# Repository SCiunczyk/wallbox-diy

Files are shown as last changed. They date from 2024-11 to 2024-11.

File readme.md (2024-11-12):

### DIV WallBox Wi-Fi ModBus ESP32 proxy

I have finished building my home DIY WallBox based on a great solution from creasol.it called [DombusEVSE](https://www.creasol.it/DomBusEVSE). Creasol has a lot of interesting smart home devices on offer and the solution they have chosen is very much based on the popular ModBus protocol. Unfortunately, in my WallBox it would be difficult for me to apply this solution because I have quite a long distance and I can't lay a cable for a ModBus connection. But fortunately my WallBox location is in range of my home WiFi network. Having already in my Home Assistant other integrations based on ESPHome, I decided to make a proxy adapter for ModBus. I used the XIAO Seed ESP32C3 board and a TTL RS485 adapter as the platform. I "stole" power from the DombusEVSE power supply (13.6V) and used a popular Pololu step-down converter. As I already had a previously purchased 3-phase energy meter with a "pulse" output, I also used the XIAO to measure and record the energy used to charge the EV.

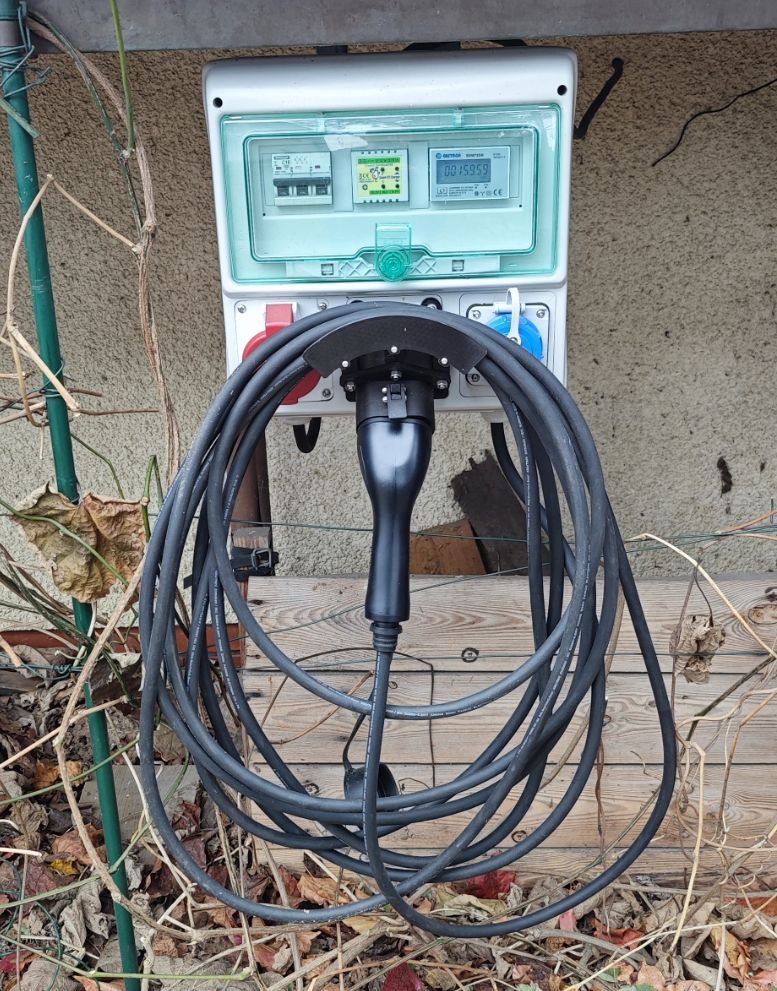
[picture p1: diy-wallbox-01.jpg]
diy-wallbox-01

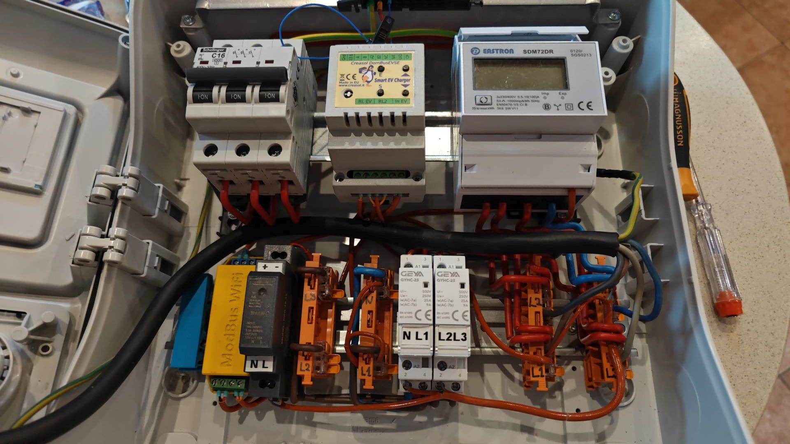
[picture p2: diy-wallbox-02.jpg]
diy-wallbox-02

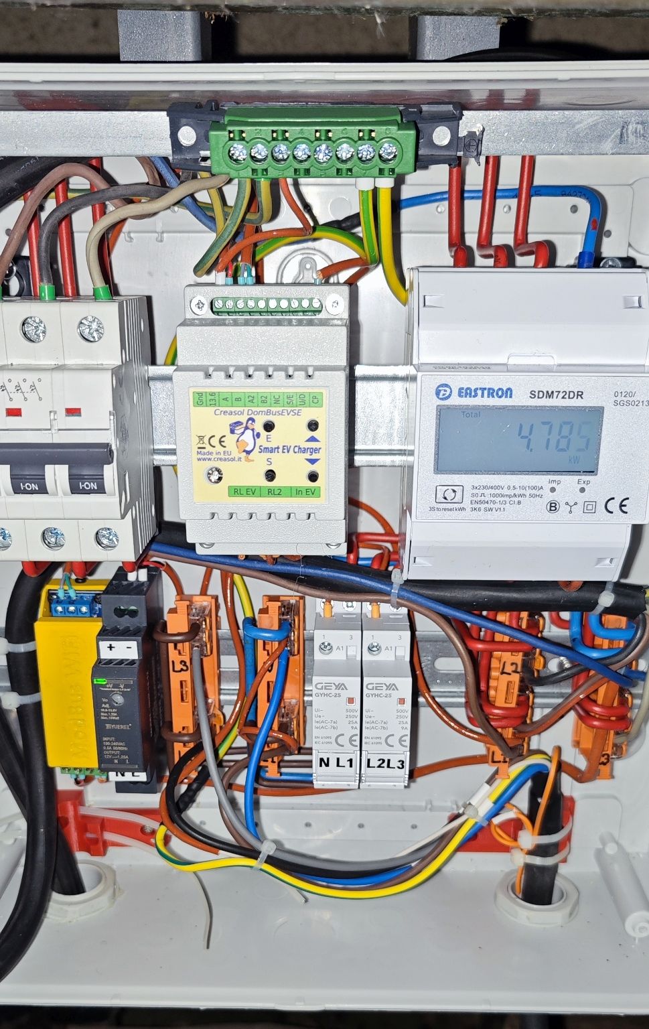
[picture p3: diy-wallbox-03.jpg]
diy-wallbox-03

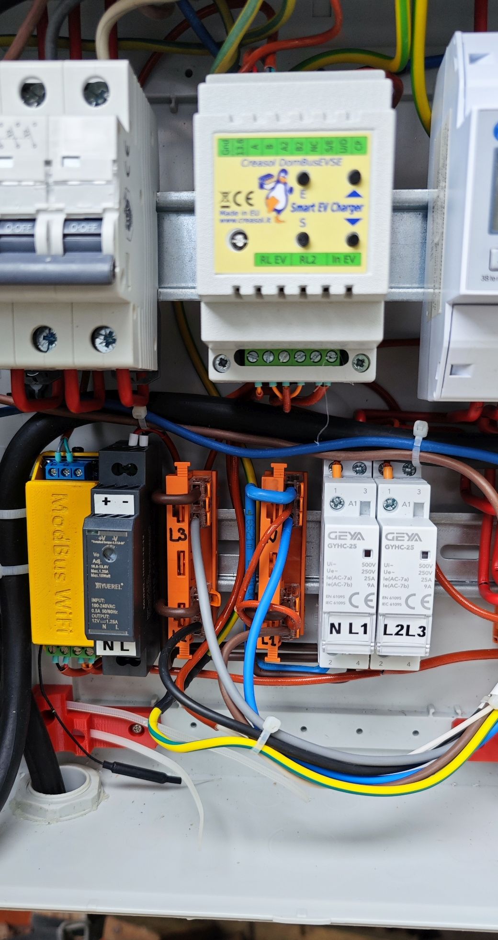
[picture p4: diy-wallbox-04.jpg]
diy-wallbox-04


It all seemed simple and straightforward, but as always life is much more interesting than we imagine.

Creasol.it provides ready-made configurations for HA, so in my first attempt I made a yaml ESPHome based on their ModBus controller https://github.com/CreasolTech/DomBusEVSE_ha.

This worked, but only partially. It seems to me that the ModBus component in ESPHome has a problem reading multiple registers with high addresses. I have described the problem on ESPHome's GitHub: https://github.com/esphome/issues/issues/6351. Registers with low addresses are read and written without problems. Writing to high addresses is correct, the problem is with sequential reading. Interestingly, reading with the custom method works fine. This allowed me to create a workaround for the problem. For high registers I defined a double set of entities. Read-only sensors, which are queried by the custom method, and a complementary numeric set, which is used for writing only.

Of course, this required adapting the original HA configuration files from the creasol.it.

My hardware WallBox is built in a variant that allows switching between single-phase and three-phase charging. I also wanted a mobile version of the dashboard. I took the opportunity to practice building my own dashboard in HA using the famous custom:button-card, custom:layout-card, custom:text-divider-row - all downloadable from HACS.

Desktop version of Home Assistant Dashboard:

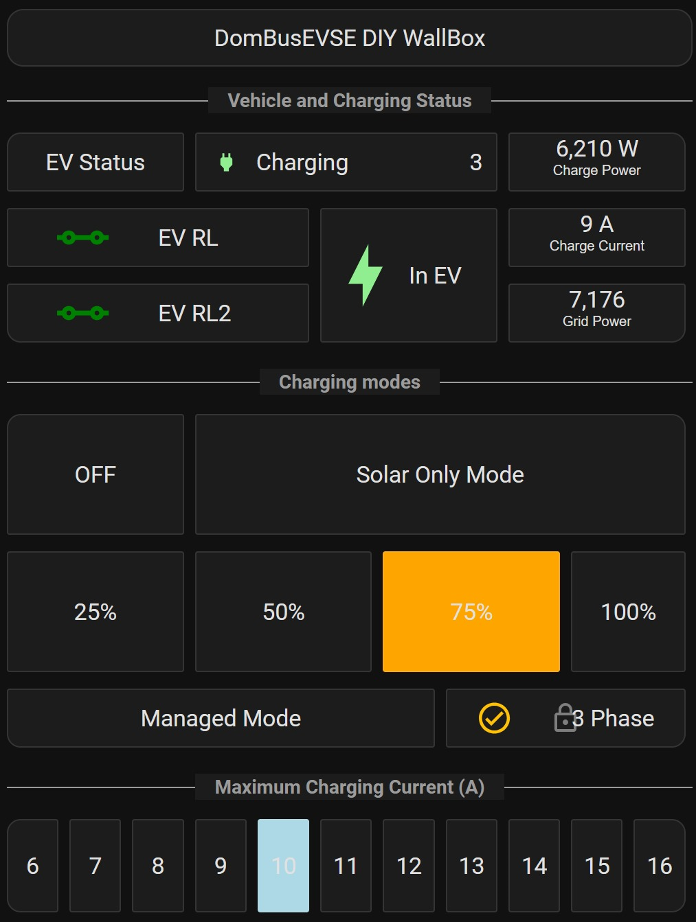
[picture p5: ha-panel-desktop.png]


and it's mobile version:

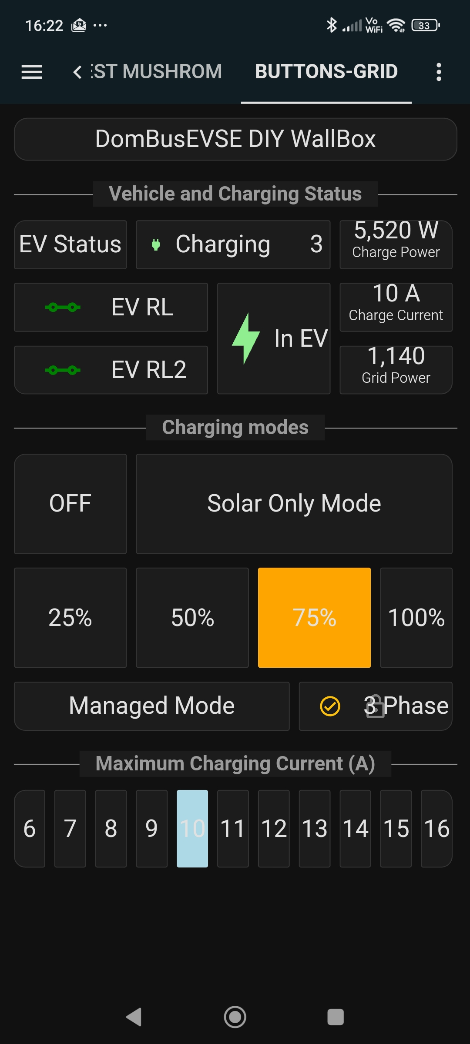
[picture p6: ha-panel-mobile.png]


I built the Wi-Fi ModBus proxy module from this schematic, soldered it to a piece of universal PCB and put it in a small 3D printed PETG case. In my case, I replaced the original XIAO Wi-Fi antenna with a slightly more efficient one (from the NanoPi Duo2 module) for more reliable communication. If you want to use my files in your project, you can do so without any restrictions. 

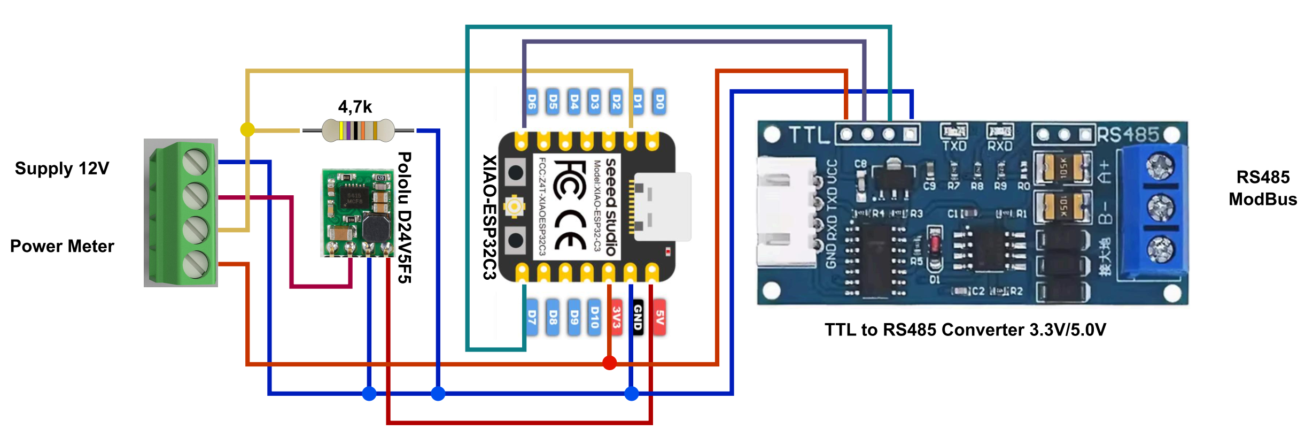
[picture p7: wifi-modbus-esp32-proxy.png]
wifi-modbus-esp32-proxy

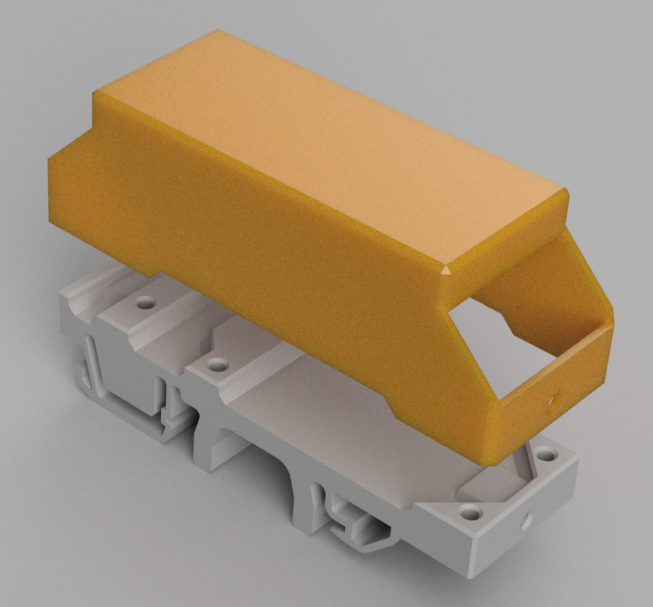
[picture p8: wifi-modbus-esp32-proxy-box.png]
wifi-modbus-esp32-proxy-box


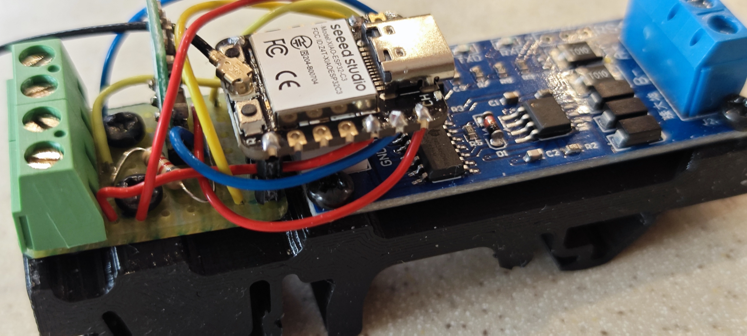
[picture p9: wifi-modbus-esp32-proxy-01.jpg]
wifi-modbus-esp32-proxy-01

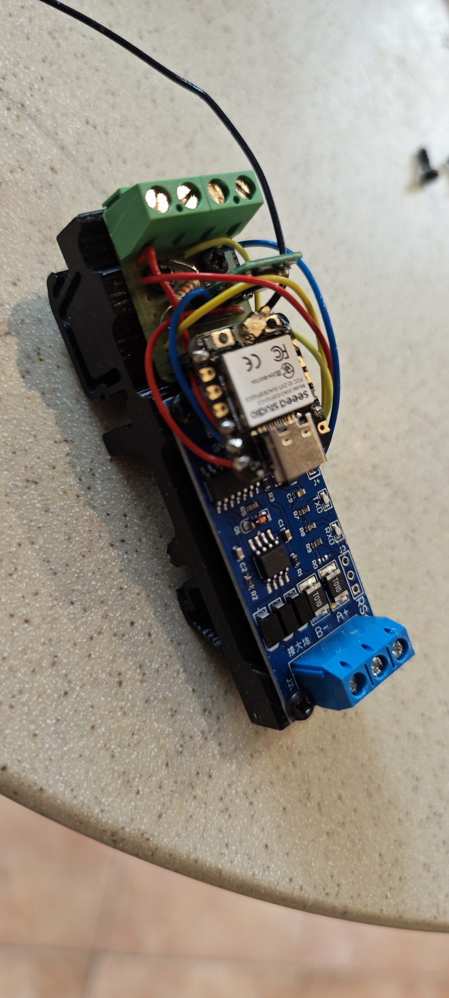
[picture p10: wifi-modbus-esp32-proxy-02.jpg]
wifi-modbus-esp32-proxy-02

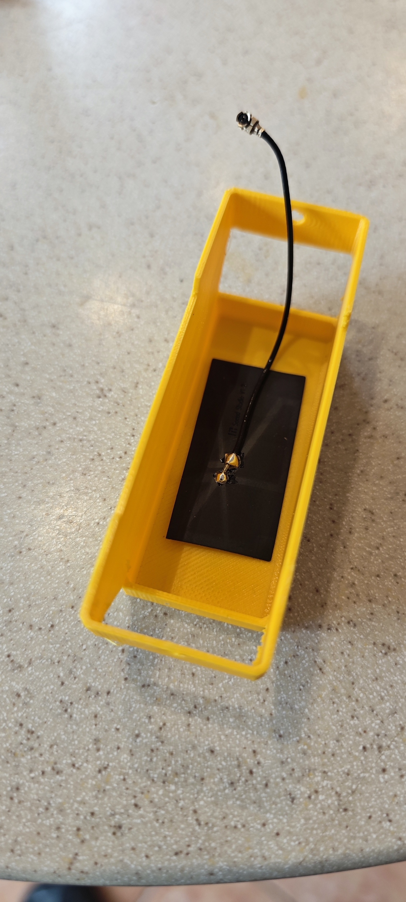
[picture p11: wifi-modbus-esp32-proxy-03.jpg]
wifi-modbus-esp32-proxy-03

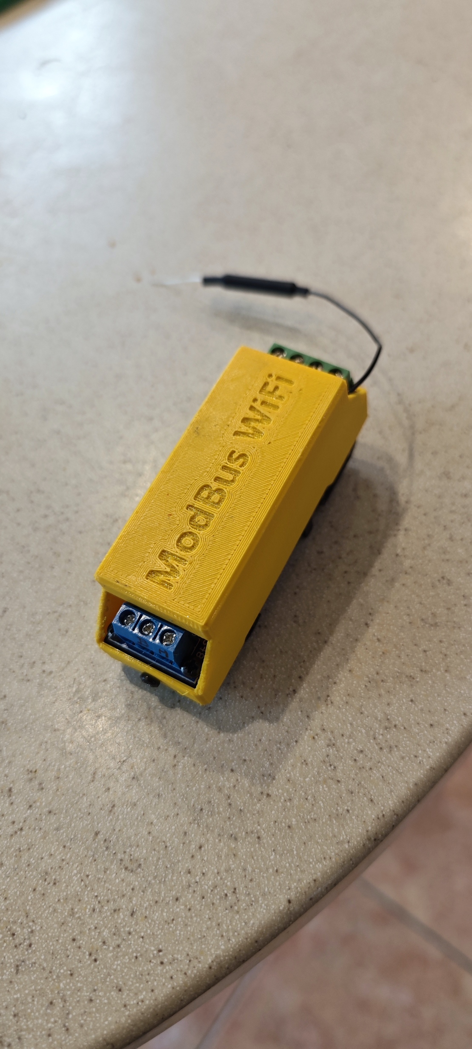
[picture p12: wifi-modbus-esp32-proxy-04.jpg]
wifi-modbus-esp32-proxy-04

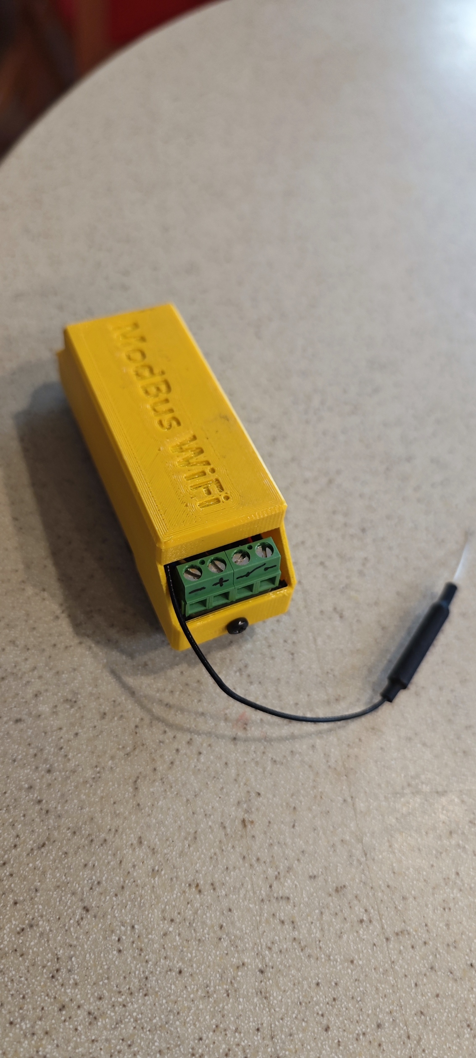
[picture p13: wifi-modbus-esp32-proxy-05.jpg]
wifi-modbus-esp32-proxy-05


I will follow the changes on ESPHome and if some good soul finds/corrects the source of the problem with reading high registers I, for my part, will apply modifications to remove the workarounds. Unfortunately I'm probably too lame to detect the source of the problem in the ESPHome code myself 😬.

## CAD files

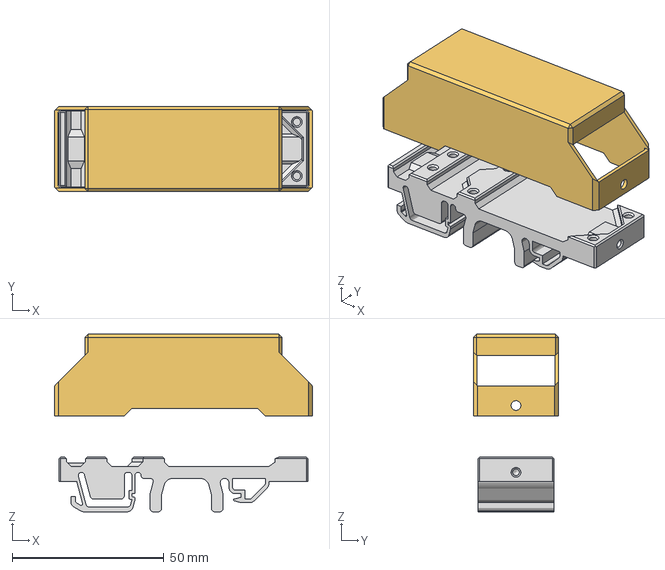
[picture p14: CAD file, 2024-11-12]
3D-Box/wifi-modbus-esp32-proxy-box.step
85.0 x 28.0 x 58.5 mm

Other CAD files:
3D-Box/wifi-modbus-esp32-proxy-box.3mf
3D-Box/wifi-modbus-esp32-proxy-box.stl

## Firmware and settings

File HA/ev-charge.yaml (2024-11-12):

substitutions:
  name: "ev-charge"
  friendly_name: ev-charge

esphome:
  name: ${name}
  friendly_name: ${friendly_name}
  # min_version: 2024.6.0
  # name_add_mac_suffix: false
  # project:
  #   name: esphome.web
  #   version: dev

esp32:
  board: seeed_xiao_esp32c3
  framework:
    type: arduino

# Enable Home Assistant API
api:
  encryption:
    key: "enter your encryption key"

  actions:
    - action: set_total
      variables:
        new_total: int
      then:
      - pulse_meter.set_total_pulses:
          id: sensor_ev_pulse_meter
          value: !lambda 'return new_total * 1000;'

# Enable logging
logger:

# Allow Over-The-Air updates
ota:
- platform: esphome

# Allow provisioning Wi-Fi via serial
#improv_serial:

wifi:
  # # use multi wifi networks
  networks:
  - ssid: !secret wifi_ssid
    password: !secret wifi_password
  # - ssid: !secret wifi_ssid2
  #   password: !secret wifi_password2

#  ap: {}

# In combination with the `ap` this allows the user
# to provision wifi credentials to the device via WiFi AP.
#captive_portal:

# Sets up Bluetooth LE (Only on ESP32) to allow the user
# to provision wifi credentials to the device.
#esp32_improv:
#  authorizer: none

# To have a "next url" for improv serial
#web_server:

# EV Power meter configuration entry
sensor:
  - platform: pulse_meter
    name: "EV Charge Power"
    id: sensor_ev_pulse_meter # Optional ID, necessary if you want to calculate the total daily energy
    unit_of_measurement: 'W'
    device_class: power
    state_class: measurement
    accuracy_decimals: 0
    pin: GPIO3

    filters:
      - multiply: 60 # (60s / impulse constant) * (1000W / 1kW)
      - throttle: 10s
      - filter_out: NaN

    internal_filter: 200ms
    timeout: 1min

    total:
      name: "EV Charge Total Energy"
      unit_of_measurement: "kWh"
      device_class: energy
      state_class: total_increasing
      accuracy_decimals: 3
      filters:
        - multiply: 0.001  # (1/1000 pulses per kWh)

# DomBusEVSE proxy module
  - platform: modbus_controller
    modbus_controller_id: modbus_evse
    name: EVCharging
    id: evse2270000
    register_type: holding
    address: 0
    unit_of_measurement: ""
    value_type: U_WORD

  # - platform: modbus_controller
  #   modbus_controller_id: modbus_evse
  #   name: EVRL2
  #   id: evse2270001
  #   register_type: holding
  #   address: 1
  #   unit_of_measurement: ""
  #   value_type: U_WORD

  - platform: modbus_controller
    modbus_controller_id: modbus_evse
    name: EVInAC
    id: evse2270002
    register_type: holding
    address: 2
    unit_of_measurement: ""
    value_type: U_WORD

  # - platform: modbus_controller
  #   modbus_controller_id: modbus_evse
  #   name: EVMode
  #   id: evse2270003
  #   register_type: holding
  #   address: 3
  #   unit_of_measurement: ""
  #   value_type: U_WORD

  - platform: modbus_controller
    modbus_controller_id: modbus_evse
    name: EVState
    id: evse2270004
    register_type: holding
    address: 4
    unit_of_measurement: ""
    value_type: U_WORD

  # - platform: modbus_controller
  #   modbus_controller_id: modbus_evse
  #   name: EVCurrent
  #   id: evse2270005
  #   register_type: holding
  #   address: 5
  #   unit_of_measurement: "A"
  #   value_type: U_WORD

  - platform: modbus_controller
    modbus_controller_id: modbus_evse
    name: EVPower
    id: evse2270006
    register_type: holding
    address: 6
    unit_of_measurement: "W"
    value_type: U_WORD

  - platform: modbus_controller
    modbus_controller_id: modbus_evse
    name: EVPowerSolar
    id: evse2270007
    register_type: holding
    address: 7
    unit_of_measurement: "W"
    value_type: U_WORD

  - platform: modbus_controller
    modbus_controller_id: modbus_evse
    name: EVPowerGrid
    id: evse2270008
    register_type: holding
    address: 8
    unit_of_measurement: "W"
    value_type: U_WORD

  - platform: modbus_controller
    modbus_controller_id: modbus_evse
    name: EVVoltage
    id: evse2270009
    register_type: holding
    address: 9
    device_class: voltage
    unit_of_measurement: "V"
    value_type: U_WORD

  - platform: modbus_controller
    modbus_controller_id: modbus_evse
    name: EVPF
    id: evse2270010
    register_type: holding
    address: 10
    unit_of_measurement: "%"
    value_type: U_WORD

  # - platform: modbus_controller
  #   modbus_controller_id: modbus_evse
  #   name: EVRL2
  #   id: evse2270011
  #   register_type: holding
  #   address: 11
  #   unit_of_measurement: ""
  #   value_type: U_WORD

  # - platform: modbus_controller
  #   modbus_controller_id: modbus_evse
  #   name: EV3PSELECT
  #   id: evse2270513
  #   register_type: holding
  #   address: 513
  #   unit_of_measurement: ""
  #   value_type: U_WORD

  # - platform: modbus_controller
  #   modbus_controller_id: modbus_evse
  #   id: evse2279002
  #   name: EVMAXPOWER
  #   address: 9002
  #   register_type: holding
  #   value_type: U_WORD
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

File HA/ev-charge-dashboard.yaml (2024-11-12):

title: Wallbox
views:
  - type: custom:grid-layout
    path: buttons-grid
    title: Wallbox
    layout:
      gridrows: auto
      grid-template-columns: 30% 40% 30%
      grid-template-areas: |
        "col1 col2 col3"
      mediaquery:
        '(max-width: 600px)':
          grid-template-columns: 100%
          grid-template-areas: |
            "col2"
    cards:
      - type: custom:layout-card
        layout_type: custom:grid-layout
        style:
          margin: 0px
          padding: 0px
          card_margin: 0px
        cards:
          - type: custom:button-card
            name: DomBusEVSE DIY WallBox
            styles:
              card:
                - height: 100%
            view_layout:
              grid-column: 1 / 13
              grid-row: 1 / 1
          - type: custom:text-divider-row
            text: Vehicle and Charging Status
            styles:
              card:
                - height: 100%
            view_layout:
              grid-column: 1 / 13
              grid-row: 2 / 2
          - type: custom:button-card
            name: EV Status
            styles:
              card:
                - height: 100%
                - border-radius: 10px 2px 2px 2px;
            view_layout:
              grid-column: 1 / 4
              grid-row: 3 / 3
          - type: custom:button-card
            entity: sensor.ev_charge_evstate
            state:
              - value: 0
                icon: mdi:lightbulb-question-outline
                color: gray
                name: 'Off'
              - value: 1
                icon: mdi:power-plug-off-outline
                color: gray
                name: Disconnected
              - value: 2
                icon: mdi:power-plug-outline
                color: blue
                name: Connected
              - value: 3
                icon: mdi:power-plug
                color: lightgreen
                name: Charging
              - value: 4
                icon: mdi:power-plug
                color: green
                name: Charging + Vent
              - value: 5
                icon: mdi:alarm-light-outline
                color: red
                name: Alarm EV !!!
              - value: 6
                icon: mdi:alarm-light-off
                color: red
                name: Alarm Power Outage
              - value: 7
                icon: mdi:alarm-light
                color: red
                name: Alarm Relay Welded
            show_entity_picture: true
            show_icon: true
            show_name: true
            show_state: true
            styles:
              card:
                - height: 100%
                - border-radius: 2px 2px 2px 2px;
              grid:
                - grid-template-areas: '"i n s"'
                - grid-template-columns: .3fr 1fr .2fr
                - grid-template-rows: 1fr
              icon:
                - align-self: middle
                - justify-self: end
              name:
                - align-self: middle
                - justify-self: start
                - padding-bottom: 0px
            tap_action:
              action: none
            view_layout:
              grid-column: 4 / 9
              grid-row: 3 / 3
          - type: custom:button-card
            name: ''
            label: Charge Power
            entity: sensor.ev_charge_evpower
            show_entity_picture: false
            show_icon: false
            show_name: false
            show_state: true
            show_units: true
            show_label: true
            units: W
            styles:
              label:
                - font: 10px Arial
              card:
                - height: 100%
                - border-radius: 2px 10px 2px 2px;
            view_layout:
              grid-column: 9 / 12
              grid-row: 3 / 3
          - type: custom:button-card
            name: EV RL
            entity: sensor.ev_charge_evcharging
            state:
              - value: 0
                icon: mdi:electric-switch
                color: gray
              - value: 1
                icon: mdi:electric-switch-closed
                color: green
            tap_action:
              action: none
            show_entity_picture: true
            show_icon: true
            styles:
              card:
                - height: 100%
                - border-radius: 2px 2px 2px 2px;
                - padding: 0px
              grid:
                - grid-template-areas: '"i n"'
                - grid-template-columns: 1fr 1fr
                - grid-template-rows: 1fr
              icon:
                - align-self: middle
                - justify-self: end
              name:
                - align-self: middle
                - justify-self: start
                - padding-bottom: 0px
            view_layout:
              grid-column: 1 / 6
              grid-row: 4 / 4
          - type: custom:button-card
            name: EV RL2
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
